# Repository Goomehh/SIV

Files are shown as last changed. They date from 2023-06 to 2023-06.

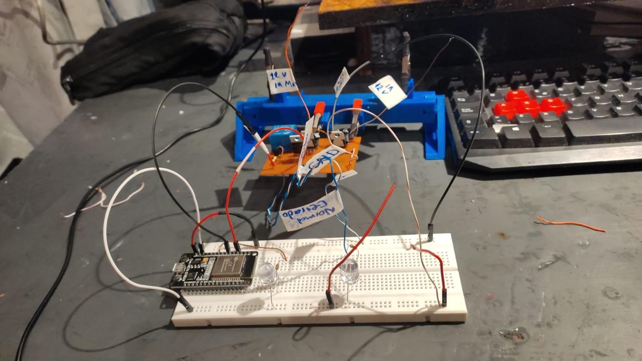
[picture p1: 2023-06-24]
Fotos/Prueba circuito sin teclado.jpg

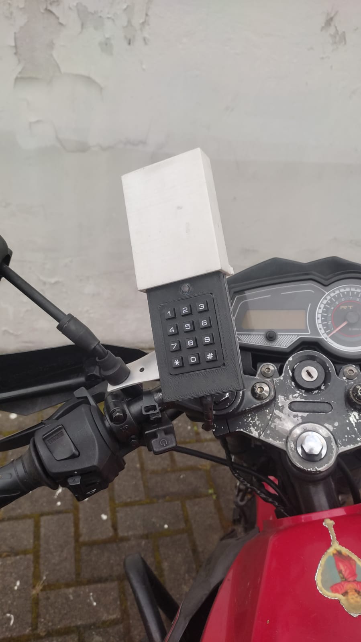
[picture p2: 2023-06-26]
Fotos/Moto con teclado integrado.jpeg

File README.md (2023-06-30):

# SIV

Sistema de identificacion vehicular

# Info

Video presentacion del proyecto: https://youtu.be/XcQt5sAtSic (Principal)

El modelado de la caja y la placa de las conexiones usadas se encuentran en el apartado "Fotos" y "Videos"

# Poster Ingenia Futuro

Poster enfocado a la problematica junto a la propuesta de solucion presentada

Poster

# Idea principal del funcionamiento del sistema (flow-chart)

Dos diagramas independientes pero que hacen parte del mismo objetivo.
Como se puede ver en la primera parte del diagrama, el proyecto esta principalemtne orientado a las motos, esto debido a su inidice de hurto en la capital y la accesibilidad que se tiene a sus componentes internos.



Por otro lado esta el sistema de la aplicacion movil, este cuanto mas es parte escencial del proyecto, pues es la que permite el ingreso de nuevos usuarios al sistema y ubica la moto en tiempo real para transmitirlo graficamente

# Boceto superficial del funcionamiento del sistema

Se hace una idea de como puede quedar instalado el circuito en la moto.
De la misma forma se grafica como iria linealmente la secuencia de pasos necesaria para que el motor de la moto sea prendido.



# Diagrama de caja negra

Se plantea lo que viene siendo la alimentacion del circuito y de la misma forma la secuencia adecuada para el procesamiento de los datos, esto teniendo en cuenta el diagrama de flujo que nos explica como debe funcionar el circuito, es necesario tener en cuenta los componenetes principales de cada sector, es decir, los puntos vitales que requiere el circuito, como la alimentacion, el "cerebro", los actuadores, sensores, entre otros.



# Diagrama de caja negra con tecnologia definida

Una vez definida la dinamica y funcionamiento del circuito se empiezan a buscar componentes aptos para facilitar el ensamble, programacion y adaptacion, en nuestro caso usaremos componentes especificos como lo son el Esp32, un sensor de huellas fpm10a, un modulo sim para la tarjeta SD, entre otros (Lista completa en la seccion "Materiales").



# Esquematico del circuito 

En esta seccion se pretende diseñar de forma clara y organizada la conexion de los diferentes componentes que se van a implementar de forma que en caso de requerir fabricar una PCB, no haya mayor complicacion, el circuito fue hecho mediante la aplicacion Kicad.



# Esquematico de la placa PCB

En este esqumatico se puede apreciar la ubicacion de cada uno de los compenetes presentados anteriormente, a excepcion de los pulsadores que simulan al teclado, para este se ponen los puertos para soldar, por otro lado tambien se aprecian las conexiones que se realizan de forma que se ahorra bastante espacio, este tipo de conexiones se manejaron por ambos lados con ese mismo objetivo en mente.



# Vista 3D del a PCB



# Pruebas

A continuacion se anexan algunas fotos sobre los montajes del circuito al vehiculo, sin embargo la mayoria de este archivo multimedia lo puede encontrar en las carpetas designadas.









(Aclaracion: en esta documentacion no esta incluida la PCB mencionada con anterioridad)

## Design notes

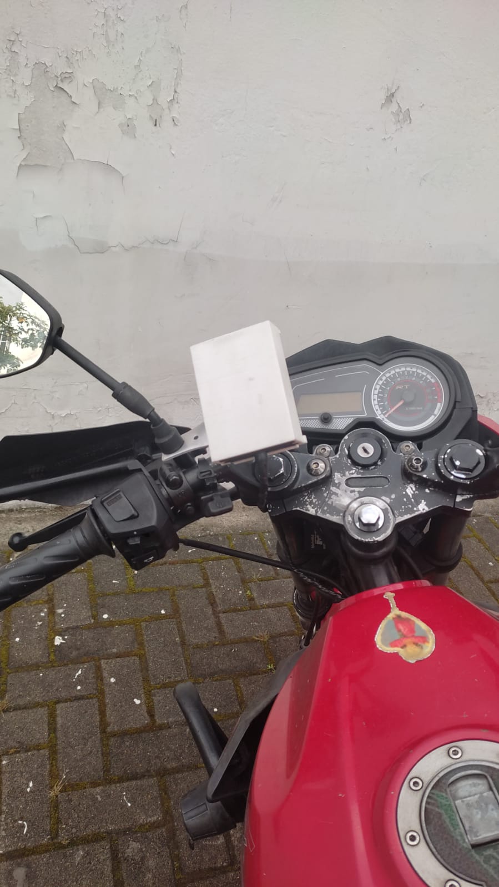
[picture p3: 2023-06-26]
Fotos/Moto con teclado integrado 2.jpeg

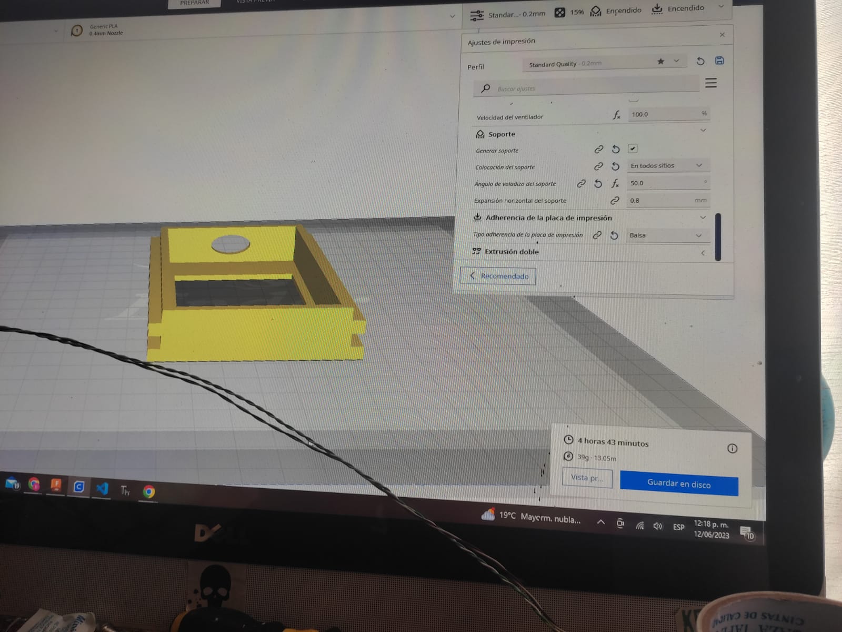
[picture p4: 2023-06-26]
Fotos/WhatsApp Image 2023-06-26 at 7.27.10 AM.jpeg

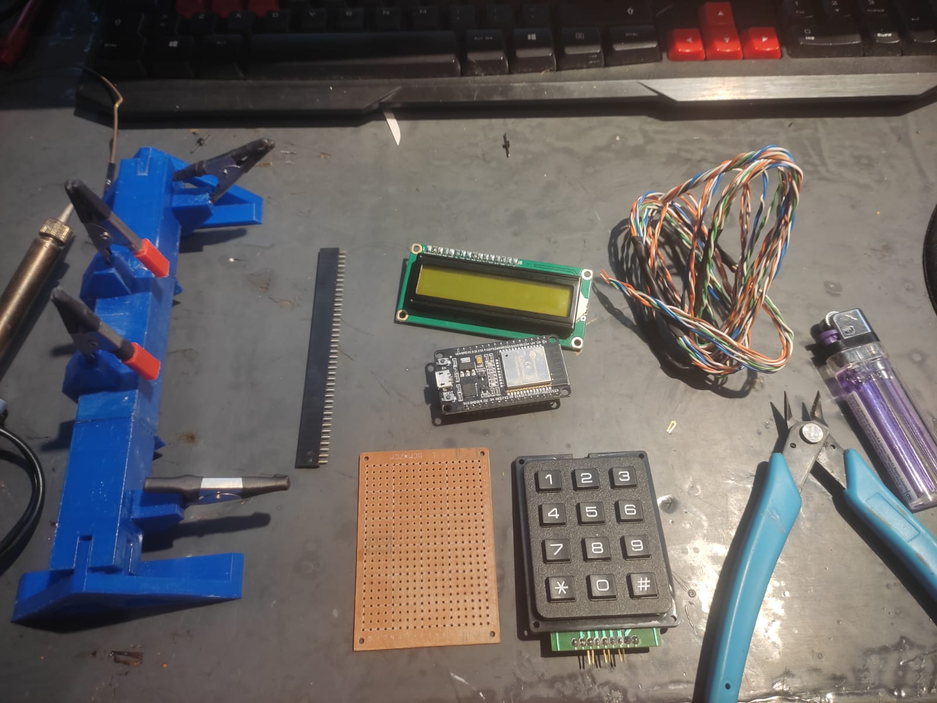
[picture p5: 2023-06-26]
Fotos/WhatsApp Image 2023-06-26 at 7.26.59 AM.jpeg

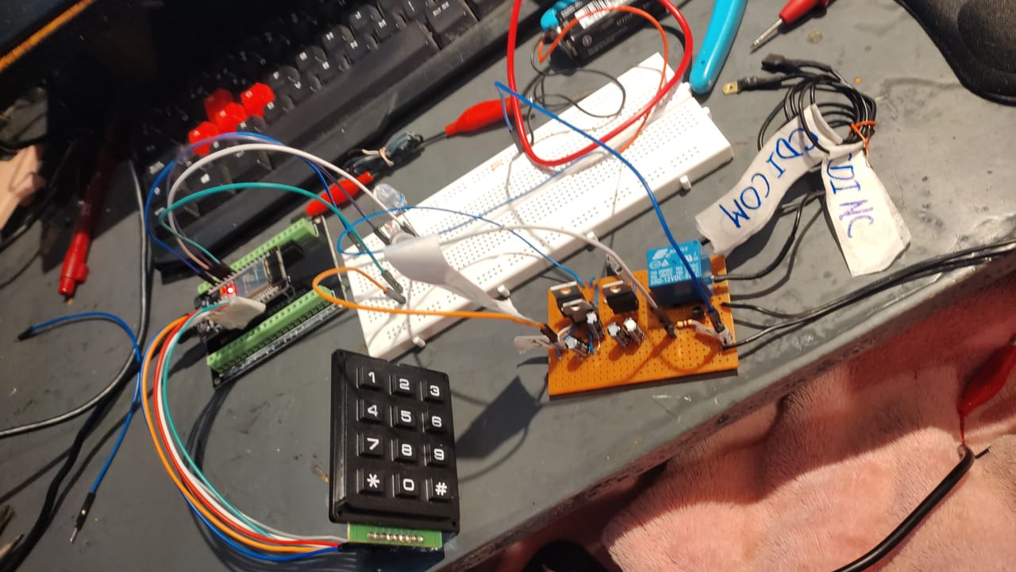
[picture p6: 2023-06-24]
Fotos/Terminacion del circuito.jpg

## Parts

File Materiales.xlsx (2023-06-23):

Materiales | Referencia | Costo C/U | Cantidad | Costo total
GPS | MODULO GPS NEO 6M UBLOX | 24000 | 1 | 24000
Sensor de huella | Sensor Biométrico Lector de Huella FPM10A | 62000 | 1 | 62000
Relee | Relee | 4300 | 1 | 4300
Modulo sim | GSM GPRS SIM 800l | 19200 | 1 | 19200
esp32 | esp32 devkit v1 | 31000 | 1 | 31000
arduino | Arduino UNO | 33000 | 1 | 33000
LED | LED RGB | 1000 | 1 | 1000
Bateria 9V | Bateria 9V | 8000 | 1 | 8000
Teclado | Teclado Matriz 4x4 Matricial | 15000 | 1 | 15000
Tac | Rfid Rc522 | 9500 | 1 | 9500
Modulo Lora | Rf Radiofrecuencia Lora Ra-01 Sx1278 433mhz 10km | 32000 | 2 | 64000

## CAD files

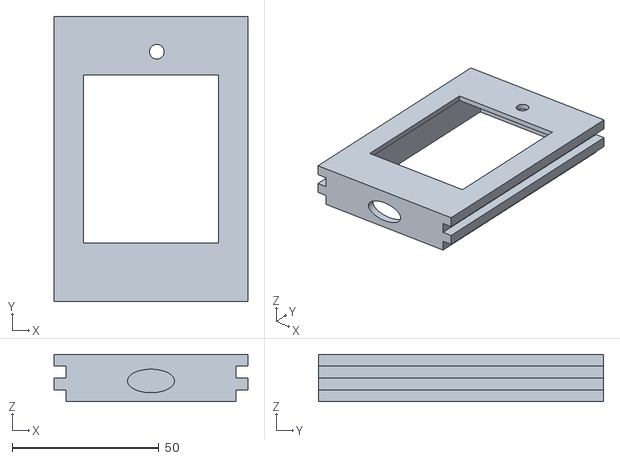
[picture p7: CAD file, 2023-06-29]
Modelado Caja e impresion/SOPORTE TECLADO v1.stl
66.0 x 97.0 x 16.0

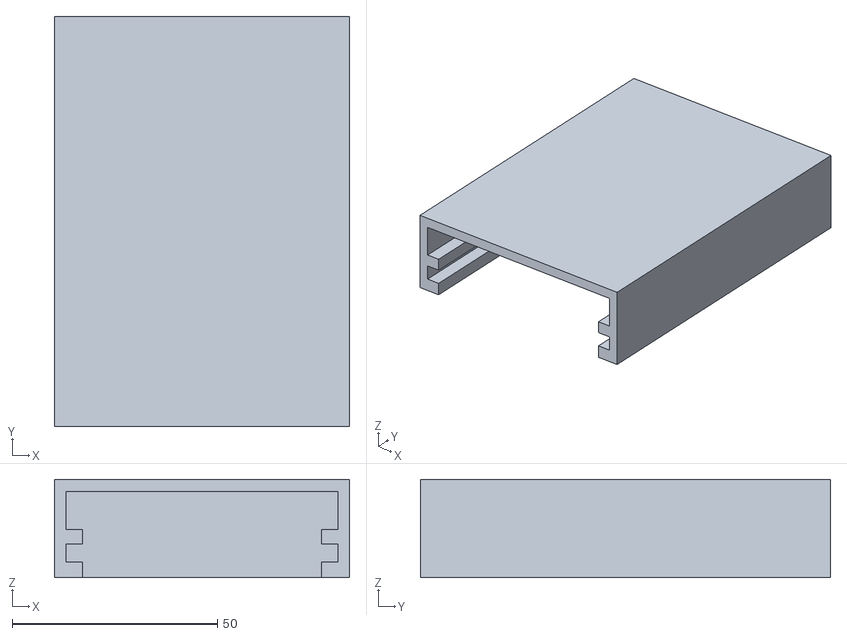
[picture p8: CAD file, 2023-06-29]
Modelado Caja e impresion/TAPA v1.stl
72.0 x 100.0 x 24.0

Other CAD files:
Modelado Caja e impresion/SOPORTE TECLADO v3.f3d
Modelado Caja e impresion/TAPA v2.f3d

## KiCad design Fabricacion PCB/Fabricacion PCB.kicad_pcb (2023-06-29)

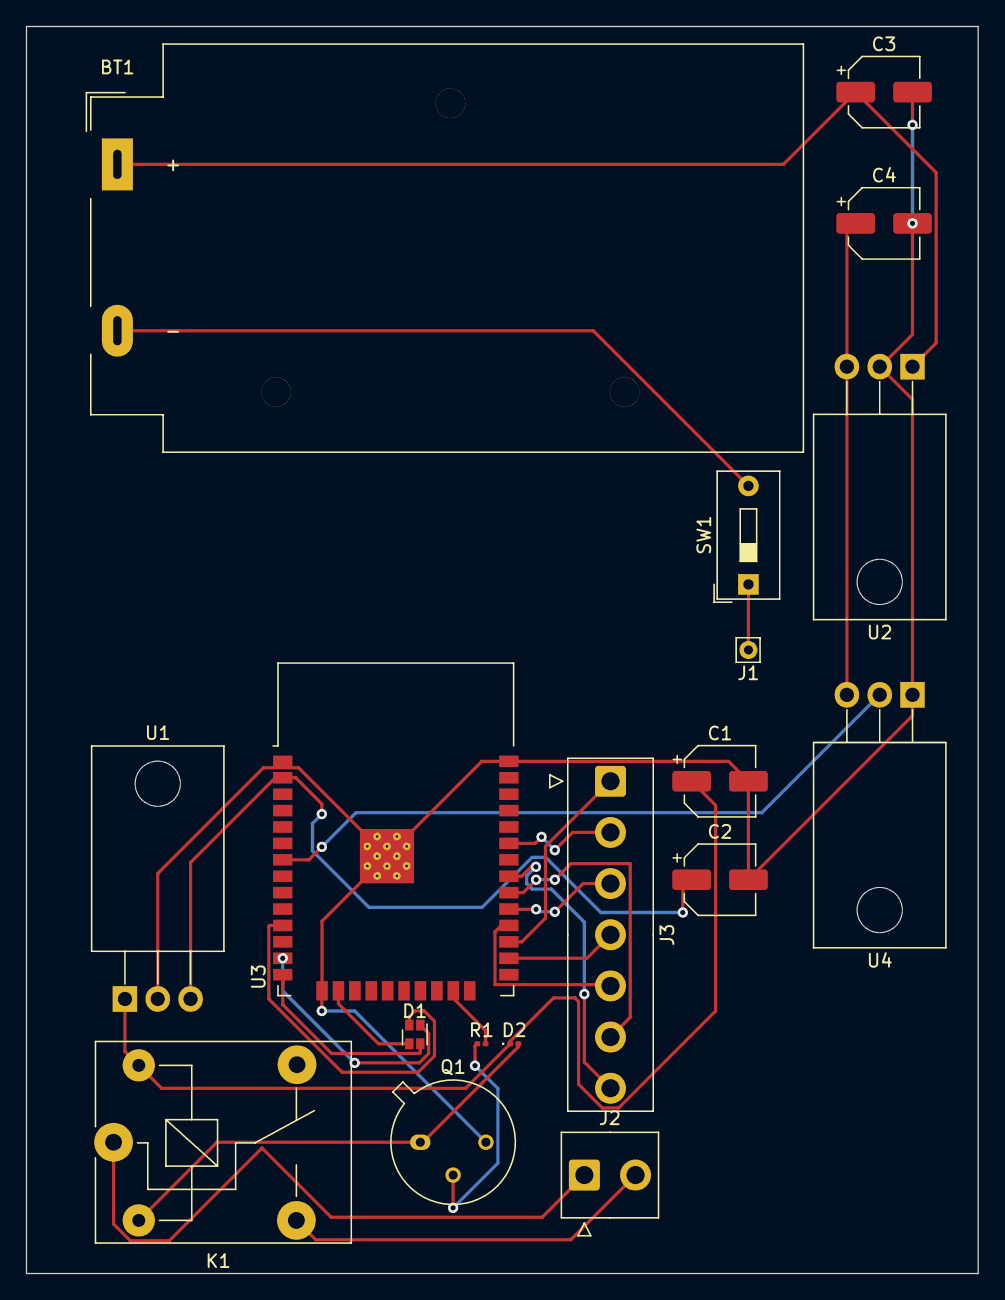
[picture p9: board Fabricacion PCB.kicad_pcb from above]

Board: 2 copper layers, 73.7 x 96.5 mm, 18 parts (0 on the bottom side), 24 nets.

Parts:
BT1: Battery_Cell; BatteryHolder_MPD_BA9VPC_1xPP3
C1, C2, C3, C4: C_Polarized; CP_Elec_5x5.4
D1: LED_ABGR; LED_LiteOn_LTST-C19HE1WT
D2: D_Zener; LED_0201_0603Metric
J1: Screw_Terminal_01x01; Pin_D0.7mm_L6.5mm_W1.8mm_FlatFork
J2: Screw_Terminal_01x02; TE_826576-2_1x02_P3.96mm_Vertical
J3: Conn_01x07_Socket; TE_826576-7_1x07_P3.96mm_Vertical
K1: SANYOU_SRD_Form_C; Relay_SPDT_SANYOU_SRD_Series_Form_C
Q1: 2N2219; TO-39-3
R1: R_US; R_0201_0603Metric
SW1: SW_SPST; SW_DIP_SPSTx01_Slide_9.78x4.72mm_W7.62mm_P2.54mm
U1, U2: L7805; TO-220-3_Horizontal_TabDown
U3: ESP32-WROOM-32
U4: LM1117T-3.3; TO-220-3_Horizontal_TabDown

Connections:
+12VA: C1.1, D2.1 (K), K1.5, U1.1 (IN)
GND: C1.2, C2.2, C3.2, C4.2, Q1.3 (C), U1.2 (GND), U2.2 (GND), U3.1 (GND), U3.15 (GND), U3.38 (GND), U3.39 (GND), U4.1 (GND)
unnamed: BT1.1 (+), C3.1, U2.1 (IN)
unnamed: BT1.2 (-), SW1.2 (B)
unnamed: D1.1 (A), U3.11 (IO26)
unnamed: D1.2 (BK), U3.13 (IO14)
unnamed: D1.3 (GK), U3.14 (IO12)
unnamed: D1.4 (RK), U3.16 (IO13)
unnamed: D2.2 (A), K1.2, Q1.1 (E)
unnamed: J1.1, SW1.1 (A)
unnamed: J2.1, K1.1
unnamed: J2.2, K1.3
unnamed: J3.1, U3.27 (IO16)
unnamed: J3.2, U3.33 (IO21)
unnamed: J3.3, U3.29 (IO5)
unnamed: J3.4, U3.26 (IO4)
unnamed: J3.5, U3.28 (IO17)
unnamed: J3.6, U3.30 (IO18)
unnamed: J3.7, U3.31 (IO19)
unnamed: Q1.2 (B), R1.1
unnamed: C2.1, U1.3 (OUT), U3.2 (VDD)
unnamed: C4.1, U2.3 (OUT), U4.3 (VI)
unnamed: R1.2, U3.23 (IO15)
unnamed: U3.7 (IO35), U4.2 (VO)

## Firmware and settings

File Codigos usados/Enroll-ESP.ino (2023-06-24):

#include <SoftwareSerial.h>
#include <Adafruit_Fingerprint.h>

uint8_t id;
// pin 33 Input do sensor (fio verde) ou rx
// pin 32 Output que vem do arduino (fio amarelo ou branco) tx
//mySerial(rx,tx)
SoftwareSerial mySerial(33,32);
Adafruit_Fingerprint finger = Adafruit_Fingerprint(&mySerial);
void setup()
{
  Serial.begin(115200);
  Serial.println("Teste do sensor");
  // set the data rate for the sensor serial port
  finger.begin(57600);
  if (finger.verifyPassword()) {
    Serial.println("O sensor foi encontrado!");
  } 
  else {
    Serial.println("O sensor não foi encontrado :(");
    while (1);
  }
}
uint8_t readnumber(void) {
  uint8_t num = 0;
  while (num == 0) {
    while (! Serial.available());
    num = Serial.parseInt();
  }
  return num;
}
void loop()
{
  Serial.println("Digite o número de ID que deseja salvar...");
  id = readnumber();
  if (id == 0) {// ID #0 !
    return;
  }

  Serial.print("Gravação ID #");
  Serial.println(id);
  while (! getFingerprintEnroll(id) );
}
uint8_t getFingerprintEnroll(int id) {
  int p = -1;
  Serial.println("Aguardando a leitura de uma nova digital");
  while (p != FINGERPRINT_OK) {
    p = finger.getImage();
    switch (p) {
      case FINGERPRINT_OK:
      Serial.println ("Impressão gravada");
      break;
      case FINGERPRINT_NOFINGER:
      Serial.println (".");
      break;
      case FINGERPRINT_PACKETRECIEVEERR:
      Serial.println ("erro na comunicação");
      break;
      case FINGERPRINT_IMAGEFAIL:
      Serial.println ("erro na imagem");
      break;
      default:
      Serial.println ("erro desconhecido");
      break;
    }
  }
  // OK success!
  p = finger.image2Tz(1);
  switch (p) {
    case FINGERPRINT_OK:
    Serial.println ("Imagem convertida");
    break;
    case FINGERPRINT_IMAGEMESS:
    Serial.println ("Imagem distorcida");
    return p;
    case FINGERPRINT_PACKETRECIEVEERR:
    Serial.println ("erro na comunicação");
    return p;
    case FINGERPRINT_FEATUREFAIL:
    Serial.println ("Não foi possível reconhecer a digital");
    return p;
    case FINGERPRINT_INVALIDIMAGE:
    Serial.println ("Não foi possível reconhecer a digital");

    return p;
    default:
    Serial.println ("erro desconhecido");
    return p;
  }
  Serial.println ("Remova o seu dedo");
  delay(2000);
  p = 0;
  while (p != FINGERPRINT_NOFINGER) {
    p = finger.getImage();
  }
  p = -1;
  Serial.println ("Coloque o mesmo dedo novamente");
  while (p != FINGERPRINT_OK) {
    p = finger.getImage();
    switch (p) {
      case FINGERPRINT_OK:
      Serial.println ("Imagem convertida");
      break;
      case FINGERPRINT_NOFINGER:
      Serial.print (".");
      break;
      case FINGERPRINT_PACKETRECIEVEERR:
      Serial.println ("erro na comunicação");
      break;
      case FINGERPRINT_IMAGEFAIL:
      Serial.println ("erro na imagem");
      break;
      default:
      Serial.println ("erro desconhecido");
      break;
    }
  }
  // OK success!
  p = finger.image2Tz(2);
  switch (p) {
    case FINGERPRINT_OK:
    Serial.println ("Imagem convertida");
    break;
    case FINGERPRINT_IMAGEMESS:
    Serial.println ("Imagem distorcida");
    return p;
    case FINGERPRINT_PACKETRECIEVEERR:
    Serial.println ("erro na comunicação");

    return p;
    case FINGERPRINT_FEATUREFAIL:
    Serial.println ("Não foi possível reconhecer a digital");
    return p;
    case FINGERPRINT_INVALIDIMAGE:
    Serial.println ("Não foi possível reconhecer a digital");
    return p;
    default:
    Serial.println ("erro desconhecido");
    return p;
  }
  // OK converted!
  Serial.print("Criando modelo para #"); Serial.println(id);
  p = finger.createModel();
  if (p == FINGERPRINT_OK) {
    Serial.println ("Digitais conferem!");
  } else if (p == FINGERPRINT_PACKETRECIEVEERR) {
    Serial.println ("erro na comunicação");
    return p;
  } else if (p == FINGERPRINT_ENROLLMISMATCH) {
    Serial.println ("As impressões digitais não batem.");
    return p;
  } else {
    Serial.println ("erro desconhecido");
    return p;
  }
  Serial.print("ID "); Serial.println(id);
  p = finger.storeModel(id);
  if (p == FINGERPRINT_OK) {
    Serial.println ("A digital foi gravada!");
  } else if (p == FINGERPRINT_PACKETRECIEVEERR) {
    Serial.println ("erro na comunicação");
    return p;
  } else if (p == FINGERPRINT_BADLOCATION) {
    Serial.println ("Não foi possível armazenar nesse local");
    return p;
  } else if (p == FINGERPRINT_FLASHERR) {
    Serial.println ("Erro ao gravar na memória");
    return p;
  } else {
    Serial.println ("erro desconhecido");
    return p;
  }
}

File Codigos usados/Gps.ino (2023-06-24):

#include <TinyGPS++.h>
#include <SoftwareSerial.h>
// Choose two Arduino pins to use for software serial
int RXPin = 7;
int TXPin = 6;

int GPSBaud = 9600;

// Create a TinyGPS++ object
TinyGPSPlus gps;

// Create a software serial port called "gpsSerial"
SoftwareSerial gpsSerial(RXPin, TXPin);

void setup()
{
  // Start the Arduino hardware serial port at 9600 baud
  Serial.begin(9600);

  // Start the software serial port at the GPS's default baud
  gpsSerial.begin(GPSBaud);
}

void loop()
{
  // This sketch displays information every time a new sentence is correctly encoded.
  while (gpsSerial.available() > 0) 
    if (gps.encode(gpsSerial.read()))
      displayInfo();

  // If 5000 milliseconds pass and there are no characters coming in
  // over the software serial port, show a "No GPS detected" error
  if (millis() > 5000 && gps.charsProcessed() < 10)
  {
    Serial.println("No GPS detected");
  }
}

void displayInfo()
{
  if (gps.location.isValid())
  {
    Serial.print("Latitude: ");
    Serial.println(gps.location.lat(), 6);
    Serial.print("Longitude: ");
    Serial.println(gps.location.lng(), 6);
    Serial.print("Altitude: ");
    Serial.println(gps.altitude.meters());
  }
  else
  {
    Serial.println("Location: Not Available");
  }
  
  Serial.print("Date: ");
  if (gps.date.isValid())
  {
    Serial.print(gps.date.month());
    Serial.print("/");
    Serial.print(gps.date.day());
    Serial.print("/");
    Serial.println(gps.date.year());
  }
  else
  {
    Serial.println("Not Available");
  }

  Serial.print("Time: ");
  if (gps.time.isValid())
  {
    if (gps.time.hour() < 10) Serial.print(F("0"));
    Serial.print(gps.time.hour());
    Serial.print(":");
    if (gps.time.minute() < 10) Serial.print(F("0"));
    Serial.print(gps.time.minute());
    Serial.print(":");
    if (gps.time.second() < 10) Serial.print(F("0"));
    Serial.print(gps.time.second());
    Serial.print(".");
    if (gps.time.centisecond() < 10) Serial.print(F("0"));
    Serial.println(gps.time.centisecond());
  }
  else
  {
    Serial.println("Not Available");
  }

  Serial.println();
  Serial.println();
  delay(1000);
}

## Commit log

2023-06-23 Create Codigo Esp32
2023-06-24 Videos que pesan menos de 25 mb
2023-06-24 Videos que pesan mas de 25 mb
2023-06-24 Cronologia sensor huellas
2023-06-24 Update Referente al sensor de huellas
2023-06-24 Update and rename Hola.txt to Referente al sensor GPS
2023-06-27 Rename Referente al sensor GPS y Modulo SIM to Sensor GPS y Modulo SIM
2023-06-27 Rename Referente al sensor de huellas to Sensor de huellas
2023-06-27 Modulo relé y reguladores de voltaje lineal
2023-06-27 Sensor GPS y Modulo SIM
2023-06-27 Sensor de huellas
2023-06-27 Codigo fuente esp32.py to Codigo fuente esp32.py (PRINCIPAL E IMPORTANTE))
2023-06-27 Sensor huella con microP.py (Fallo)
